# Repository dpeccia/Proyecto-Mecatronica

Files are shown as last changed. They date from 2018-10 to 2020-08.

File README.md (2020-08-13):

# Driller

#### Proyecto Final Grupal - Tecnicatura en Mecatrónica - Camada 2018

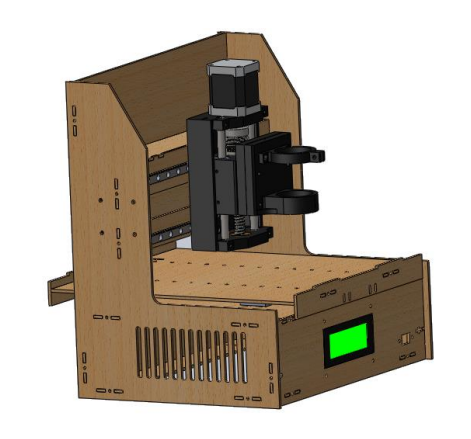
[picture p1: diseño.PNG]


Este proyecto fue realizado por toda la camada 2018 del estudio terciario _Mecatrónica_ brindado por  la _Cámara de Comercio e Industria Argentino-Alemana **(AHK)**_ en formato de Sistema Dual Alemán.

Consiste en una _Agujereadora Automática de Plaquetas Electrónicas_,  para acelerar y optimizar el tiempo del proceso de producción de plaquetas

La parte teórica, en donde fue hecho este proyecto, se cursó en el _Centro de Formación Industrial_ del _Instituto Hölters Schule_ mientras que cada alumno realizó la parte práctica del terciario en una empresa capacitadora

Más información sobre la **Tecnicatura en Mecatrónica** en [la página de la AHK](https://www.ahkargentina.com.ar/formaciones/sistema-dual-aleman/tecnicatura-en-mecatronica)

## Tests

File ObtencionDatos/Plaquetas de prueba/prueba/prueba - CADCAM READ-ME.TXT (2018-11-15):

LABCENTER PROTEUS TOOL INFORMATION FILE
=======================================

In case of difficulty, please e-mail support@labcenter.co.uk

Tool set up for Proteus layout 'prueba.pdsprj'.
CADCAM generated at 01:32:39 p.m. on jueves, 18 de octubre de 2018.

File List
---------
Top Copper              : prueba - CADCAM Top Copper.GBR
Bottom Copper           : prueba - CADCAM Bottom Copper.GBR
Top Solder Resist       : prueba - CADCAM Top Solder Resist.GBR
Bottom Solder Resist    : prueba - CADCAM Bottom Solder Resist.GBR
Mechanical 1            : prueba - CADCAM Mechanical 1.GBR
Drill                   : prueba - CADCAM Drill.DRL
Netlist                 : prueba - CADCAM Netlist.IPC

Photoplotter Setup
------------------
Format: RS274X, ASCII, 4.3, metric, absolute, eob=*, LZO
Notes:  D=Diameter, S=Side, W=Width, H=Height, C=Chamfer, I=Index

D10	CIRCLE  D=1.016mm                                                         FLASH
D11	CIRCLE  D=0.2032mm                                                        DRAW 
D12	CIRCLE  D=1.27mm                                                          FLASH
D13	CIRCLE  D=0.127mm                                                         DRAW 
D14	CIRCLE  D=0.0635mm                                                        DRAW 

NC Drill Setup
--------------
Format: Excellon, ASCII, 4.3, metric, absolute, eob=<CR><LF>, no zero suppression.
Notes:  Tool sizes are diameters. Layer sets are in brackets - 0=TOP, 15=BOTTOM, 1-14=INNER.

T01	0.381mm (0-15) Plated

Layer Stackup
-------------
Top Solder Resist        : 0.01016mm  Resist
Top Copper               : 0.03556mm  Copper
Core                     : 1.48336mm  FR4
Bottom Copper            : 0.03556mm  Copper
Bottom Solder Resist     : 0.01016mm  Resist

[END OF FILE]

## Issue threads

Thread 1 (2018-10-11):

Secuencia Ajuste

chrisgko, 2018-10-11:
Hay que cambiar las esperas de datos desde el micro por threads o algo asi, para que no se cuelgue el programa, y también para poder ajustar los puntos de calibración.

Closed 2018-11-16.

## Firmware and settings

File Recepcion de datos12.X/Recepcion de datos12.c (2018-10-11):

#include <18F4550.h>
#include <stdlib.h>
#fuses HSPLL,NOWDT,NOPROTECT,NOLVP,NODEBUG,PLL5,CPUDIV1,VREGEN,MCLR,USBDIV,  // 48 MHz  para  el  USB y 48 MHz para  el resto del sistema
#use delay(clock=48000000)
#use rs232(baud=9600, xmit=pin_c6, rcv=pin_c7, bits=8, parity=N,stream=standard) 
#use i2c(Master,sda=PIN_B4, scl=PIN_B5, force_sw,fast)
#include <i2c_Flex_LCD.c>   
//#include <LCD420-FLEX.c>

#define sentidox PIN_D0
#define sentidoy PIN_D1
#define sentidoz PIN_D2
#define motorx PIN_D3
#define motory PIN_D4
#define motorz PIN_D5
#define cerox PIN_D6
#define ceroy PIN_D7
#define ceroz PIN_C0
#define profunz PIN_C1
#define dremel PIN_E0
#define enter PIN_E1
#define habilx PIN_E2
#define habily PIN_A0
#define habilz PIN_A1
#define canalb PIN_A2
#define buzzer PIN_A3

char ch;
char mech[5];
char datox[7];
char datoy[7];
int i, j, h, flagfin, salir;
int contador, contador1;
signed int32 x, y, xini, yini, pasosx, pasosy;
float broca, pasosxflot, pasosyflot;
int flagx, flagy, flagxy, flagcomienzo, flagmecha, flagboton;
short int flagpaquete, flagajuste, flagcambiomecha;
signed int32 pasosz, zini, z, alturamecha, guarda;

void moverz(void) 
{
    output_low(habilz);
    pasosz = z - zini;
    
    while (pasosz > 0) 
    {
        output_high(sentidoz); //para abajo
        output_high(motorz);
        delay_us(1200);
        output_low(motorz);
        delay_us(1200);
        pasosz = pasosz - 1;
    }
    while (pasosz < 0) 
    {
        output_low(sentidoz); //para arriba
        output_high(motorz);
        delay_us(1200);
        output_low(motorz);
        delay_us(1200);
        pasosz = pasosz + 1;
    }
    zini = z;
}

void bajarz(void) 
{
    while (pasosz > 0) //rutina que baja el cabezal
    { 
        output_low(habilz);
        pasosz = pasosz - 1;
        output_high(sentidoz);
        output_toggle(motorz);
        delay_us(1200);
    }
}

void subirz(void) 
{
    while (pasosz > 0) //rutina que sube el cabezal
    { 
        output_low(sentidoz);
        pasosz = pasosz - 1;
        output_toggle(motorz);
        delay_us(1200);
    }
}

void conversionpasos(void) 
{
    pasosxflot = (x - xini) / 200.0;
    pasosyflot = (y - yini) / 200.0;
    if (pasosxflot >= 0)
        pasosx = (signed long int) (pasosxflot + 0.5);
    else
        pasosx = (signed long int) (pasosxflot - 0.5);

    if (pasosyflot >= 0)
        pasosy = (signed long int) (pasosyflot + 0.5);
    else
        pasosy = (signed long int) (pasosyflot - 0.5);

    pasosx = pasosx * 2;
    pasosy = pasosy * 2;
}



void moverxy(void) 
{
    clear_interrupt(INT_TIMER0);
    set_timer0(230);
    enable_interrupts(INT_TIMER0); //Habilita interrupción timer0
    flagx = 1;
    flagy = 1;
    flagxy = 1;
    while (flagxy == 1);
}

void posicionmecha(void) 
{
    x = +175000;
    y = +205000;
    conversionpasos();
    xini = x;
    yini = y;
    // pasosx=+1500;     //pasos para ir a punto de prueba
    //pasosy=+1000;     //pasos para ir a puto de prueba
    contador = 2;
    moverxy();
    putc('M');
}

void profundidadmecha(void) 
{
    printf(LCD_PUTC, "\f\1%s", "Ajustando Z");
    printf(LCD_PUTC, "\2%s", "Profundidad de mecha");
    output_low(habilz);
    output_low(habilx);
    output_low(habily);
    output_low(motorz);
    while (input(profunz) == 1) {
        output_high(sentidoz);
        output_high(motorz);
        delay_us(1200);
        output_low(motorz);
        delay_us(1200);
        alturamecha = alturamecha + 1;
    }
    // alturamecha=alturamecha-500; //le resta el espesor de la base + 1mm total 4,5 mm
    zini = alturamecha;
}

void ajusteceroz(void) 
{
    //printf(LCD_PUTC, "\f\1%s", "Ajustando eje Z");
    //printf(LCD_PUTC, "\2%s", "Espere por favor");
    output_low(habilz);
    printf(LCD_PUTC, "\f\1%s", "Buscando cero Z");
    while ((input(ceroz)) == 0) {
        output_low(sentidoz);
        output_toggle(motorz);
        delay_us(1200);
    }
    printf(LCD_PUTC, "\f\1%s", "Buscando cero Z OK");
    zini = 0;
}

void ajusteceroxy(void) 
{
    printf(LCD_PUTC, "\f\1%s", "Ajustando ejes X-Y");
    printf(LCD_PUTC, "\2%s", "Espere por favor");
    //ajusteceroz();
    output_low(habilx);
    output_low(habily);
    while ((input(cerox) == 0) || (input(ceroy)) == 0) 
    {
        if (input(cerox) == 0) 
        {
            output_high(sentidox);
            output_toggle(motorx);
        }
        if (input(ceroy) == 0) 
        {
            output_low(sentidoy);
            output_toggle(motory);
        }
        delay_us(1200);
    }
    output_low(motorx);
    output_low(motory);
    output_low(motorz);
    xini = 0;
    yini = 0;
}

void mecha(void) 
{
    while (flagmecha == 0);
    while (flagmecha == 1);
    broca = atof(mech);
}

void bip(void) 
{
    output_high(buzzer);
    contador1 = 5; // 1/48*4*65586*8*23=218453useg aprox
    clear_interrupt(INT_TIMER1); //limpio la bandera
    set_timer1(0);
    enable_interrupts(INT_TIMER1);
}

#INT_EXT2         //Atención a interrupción por cambio en RB2

void ext_isr1() //Función de interrupción
{ 
    putc('F');
    flagajuste = 0;
    salir = 1;
    // disable_interrupts(int_ext2_L2H);
}

#INT_EXT         //Atención a interrupción por cambio en RB0

void INTEXT_isr(void) //Función de interrupción
{ 
    output_low(motorz);
    if (input(canalb) == 0) 
    {
        output_low(habilz);
        output_low(sentidoz); //mecha para arriba
        z = z - 1;
        output_high(motorz);
        delay_us(1200);
        output_low(motorz);
        delay_us(1200);
    }
    if (input(canalb) == 1) 
    {
        output_low(habilz);
        output_high(sentidoz); //mecha para abajo
        z = z + 1;
        output_high(motorz);
        delay_us(1200);
        output_low(motorz);
        delay_us(1200);
    }
}
#int_TIMER0

void TIMER0_isr(void) 
{
    contador = contador - 1;

    if (contador == 0) 
    {
        contador = 2;
        if (pasosx == 0) 
        {
            flagx = 0;
        }
        if (pasosx > 0) 
        {
            output_low(sentidox);
            output_toggle(motorx);
            pasosx = pasosx - 1;
        }
        if (pasosx < 0) 
        {
            output_high(sentidox);
            output_toggle(motorx);
            pasosx = pasosx + 1;
        }

        if (pasosy == 0) 
        {
            flagy = 0;
        }
        if (pasosy > 0) 
        {
            output_high(sentidoy);
            output_toggle(motory);
            pasosy = pasosy - 1;
        }
        if (pasosy < 0) 
        {
            output_low(sentidoy);
            output_toggle(motory);
            pasosy = pasosy + 1;
        }

        if (flagx == 0 && flagy == 0) 
        {
            flagxy = 0;
            disable_interrupts(INT_TIMER0); //deshabilita interrupción timer0
        }

    }
    set_timer0(230); //Se recarga el timer0
}

#int_TIMER1

void TIMER1_isr(void) // Timer para buzzer
{
    contador1 = contador1 - 1;

    if (contador1 == 0) 
    {
        output_low(buzzer);
        disable_interrupts(INT_TIMER1);
    }
    set_timer1(0);
}
#int_rda

void serial_isr() 
{
    ch = getchar();
    
    if (ch == 'A') //Inicio Ajuste
    {
        flagajuste = 1;
    }    
    if (ch == 'S') 
    {
        flagcomienzo = 1;
    }
    if (ch == 'P') //Dato de perforacion entrante
    {
        flagpaquete = 1;
    }
    if (ch == 'F' && flagpaquete == 1) //Ciclo terminado
    {
        flagpaquete = 0;
        flagfin = 1;
    }
    if (ch == 'C')
    {
        flagpaquete = 0;
        flagcambiomecha = 1;
    }
    if (ch == 'M') //Mecha entrante    
    {        
        flagmecha = 1;
        h = 0;
    }
    if ((flagmecha) == 1 && (ch != 'M')) //Dato mecha
    {
        mech[h] = ch;
        h = h + 1;
        if (h == 5) 
        {
            flagmecha = 0;
        }
    }
    if (ch == 'X') //Valor X entrante
    {
        flagx = 1;
        i = 0;
    }
    if (ch == 'Y') //Valor Y entrante
    {
        flagy = 1;
        j = 0;
    }
    if ((flagx) == 1 && (ch != 'X')) //Dato X
    {
        datox[i] = ch;
        i = i + 1;
        if (i == 7) 
        {
            flagx = 0;
        }
    }
    if ((flagy) == 1 && (ch != 'Y')) //Dato Y
    {
        datoy[j] = ch;
        j = j + 1;
        if (j == 7) {
            flagy = 0;
            flagxy = 1;            
        }
    }
}
void perforacion(void) 
{
    output_high(dremel);
    while (flagpaquete == 0)
    {
        if(flagcambiomecha == 1)
        {
            ajusteceroz();
                ajusteceroxy();
                posicionmecha();
                putc('M');
                mecha();
                lcd_putc("\f\1Por favor coloque");
                printf(lcd_putc"\2mecha de %01.2fmm y", broca);
                lcd_putc("\3presione enter");

                while (input(enter) == 0);
                delay_ms(10);
                bip();
                while (input(enter) == 1);
                alturamecha = 0;
                profundidadmecha();
                zini = alturamecha;
                z = alturamecha - 500;
                moverz();
                ajusteceroxy();
                flagcambiomecha = 0;
                flagcomienzo = 1;
                puts("C");  // Confirmacion cambio de mechareturn;
                return;
        }
    }
    while (flagpaquete == 1) 
    {
        while (flagxy == 0)
        {
            if(flagpaquete == 0)
            {
                    return;
            }
        }        
        while (flagxy == 1) 
        {
            x = (signed long long int) atof(datox);
            y = (signed long long int) atof(datoy);
            conversionpasos();
            xini = x;
            yini = y;
            clear_interrupt(INT_TIMER0);
            set_timer0(230);
            enable_interrupts(INT_TIMER0); //Habilita interrupción timer0
            flagx = 1;
            flagy = 1;
            while (flagxy == 1);
            z = zini + 400; // Baja 4 mm
            moverz();
            z = zini - 400; //sube 4mm
            moverz();            
            flagpaquete = 0;
            putc('*');
        }
    }
    output_low(dremel);
}
void main() 
{
    delay_ms(1000);
    enable_interrupts(INT_RDA);
    setup_timer_0(RTCC_8_BIT | RTCC_DIV_256); //Configuración timer0
    setup_timer_1(T1_INTERNAL | T1_DIV_BY_8); //Configuración timer1

    enable_interrupts(INT_EXT2_L2H); //Habilita int. RB2?
    //ext_int_edge(L_TO_H);              //por flanco de subida
    enable_interrupts(GLOBAL); //Habilita interrupción general
    lcd_init();

    while (1) {
        flagfin = 0;
        flagmecha = 0;
        flagcomienzo = 0;
        xini = 0;
        yini = 0;
        zini = 0;
        flagajuste = 0;
        flagpaquete = 0;
        pasosx = 0;
        pasosz = 0;
        pasosy = 0;
        alturamecha = 0;
        x = 0;
        y = 0;
        z = 0;
        flagboton = 0;
        flagxy = 0;
        flagx = 0;
        flagy = 0;
        broca = 0;
        pasosxflot = 0;
        pasosyflot = 0;
        salir = 0;
        i = 0;
        j = 0;
        h = 0;
        output_high(habilx); //motores sin energía
        output_high(habily);
        output_high(habilz);
        output_low(dremel); //apago el dremel
        output_low(buzzer); // apago buzzer
        lcd_putc("\fHAGA CLICK EN");
        lcd_putc("\2CALIBRAR EN LA");
        lcd_putc("\3COMPUTADORA Y ESPERE");
        lcd_putc("\4UN MOMENTO.");
        while (flagcomienzo == 0);
        flagcomienzo = 0;
        ajusteceroz();
        ajusteceroxy();
        posicionmecha();
        mecha();
        printf(lcd_putc"\f\1Coloque mecha %01.2fmm", broca);
        lcd_putc("\2Presione enter para");
        lcd_putc("\3comenzar el ajuste");
        lcd_putc("\4de la placa.");
        while (input(enter) == 0);
        delay_ms(10);
        bip();
        while (input(enter) == 1);
        alturamecha = 0;
        profundidadmecha();
        zini = alturamecha;
        z = alturamecha - 500; 
        moverz();
        ajusteceroxy();
        putc('A');
        while (flagajuste == 0 && salir == 0);
        while (flagajuste == 1)
        {
            while (flagxy == 0);
            while (flagxy == 1)
            {
                x = (signed long long int) atof(datox);
                y = (signed long long int) atof(datoy);
                conversionpasos();
                xini = x;
                yini = y;
                clear_interrupt(INT_TIMER0);
                set_timer0(230);
                enable_interrupts(INT_TIMER0); //Habilita interrupción timer0
                flagx = 1;
                flagy = 1;
                while (flagxy == 1);
                lcd_putc("\f\1Gire para subir o");
                lcd_putc("\2bajar mecha.Presione");
                lcd_putc("\3enter nuevo punto.");
                lcd_putc("\4Boton rojo salir.");
                clear_interrupt(INT_EXT_L2H);
                enable_interrupts(INT_EXT_L2H);
                while (input(enter) == 0 && salir == 0);
                delay_ms(10);
                bip();
                while (input(enter) == 1 && salir == 0);
                if (input(enter) == 0 && salir == 0)
                {
                    guarda = zini;
                    zini = z;
                    z = guarda;
                    moverz();
                    putc('A');
                }
            }
        }
        
        bip();
        disable_interrupts(INT_EXT_L2H);
        
        /*while (flagfin == 0) 
        {
            /*
            if (salir == 0)
            {
                ajusteceroz();
                ajusteceroxy();
                posicionmecha();
                putc('M');
                mecha();
                lcd_putc("\f\1Por favor coloque");
                printf(lcd_putc"\2mecha de %01.2fmm y", broca);
                lcd_putc("\3presione enter");

                while (input(enter) == 0);
                delay_ms(10);
                bip();
                while (input(enter) == 1);
                alturamecha = 0;
                profundidadmecha();
                zini = alturamecha;
                z = alturamecha - 500;
                moverz();
                ajusteceroxy();
                flagcambiomecha = 0;
                flagcomienzo = 1
                puts("C");  // Confirmacion cambio de mecha
            }*/
            ajusteceroxy();
            contador = 2;
            lcd_putc("\f\1Perforadora Lista");
            lcd_putc("\2para operar haga click");
            lcd_putc("\3en \"Comenzar\"");
            while (flagcomienzo == 0);
        while (flagfin == 0)
        {
            lcd_putc("\f\1PERFORANDO");
            flagcomienzo = 0;
            perforacion();
            salir = 0;
        }
    }
}

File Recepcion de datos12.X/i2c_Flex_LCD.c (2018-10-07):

//----------------------------------------------------------------------------- 
// Title:         i2c_Flex_LCD 
// Description:   Driver for common LCD with 1/2/3 or 4 row modules using PCF8574T interface board with I2C protocol. 
// Date:          Nov-2013 
// Ver.Rev.:      1.0 
// Author:        Hugo Silva (sergio-hugo@bol.com.br) #Based on the routines of 20X4_LCD_I2C_DRIVER.h from Pumrin S. 
//----------------------------------------------------------------------------- 
// 
// lcd_init() Must be called before any other function. 
// 
// lcd_putc(c) Will display c on the next position of the LCD. 
//  
//     \f Clear LCD dispay 
//     \1 Set write position on LCD Line 1 
//     \2 Set write position on LCD Line 2 
//     \3 Set write position on LCD Line 3 
//     \4 Set write position on LCD Line 4 
// 
//     lcd_gotoxy(x,y) Set write position on LCD (upper left is 1,1) 
// 
//----------------------------------------------------------------------------- 
// LCD pins D0-D3 are not used. 
//----------------------------------------------------------------------------- 
// 
// Commment   : Control of a compatible LCD HITACHI from a bus I2C with 
//              an EXPANDER of I/O with connection I2C. The tests of these 
//              routines have been programmed using the IC PCF8574T of Phillips. 
//              I used 4 bits mode programming. The 8 bits mode programming 
//              is possible if you use 2 x PCF8574T. 
// 
// As defined in the following structure the pin connection is as follows: 
// 
//  PCF8574P     LCD 
//  ========     ====== 
//     P0        RS 
//     P1        RW 
//     P2        Enable  
//     P3        Led Backlight 
//     P4        D4 
//     P5        D5 
//     P6        D6 
//     P7        D7 
// 
//  The SCL and SDA pins should be pull-up resistor as shown below: 
// 
//             +5v 
//               | 
//               < 
//               > 4.7K        
//               <          
//To PIC         |          To i2c slave 
//pin xx ------------------ SDA pin  
//(SDA)                      
//              +5v 
//               | 
//               < 
//               > 4.7K        
//               <          
//To PIC         |          To i2c slave 
//pin xx ------------------ SCL pin  
//(SCL) 
// 
//To PIC                    To i2c slave 
//Vss pin ----------------- Vss or ground pin  
//                | 
//              ----- 
//               ---  Ground 
//                -  
//  
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
#define LCD_ADDR       0x7E//0x4E //I2C slave address for LCD module 

#define ON             1 
#define OFF            0 
#define RS             0b00000001  //P0 - PCF8574T Pin connected to RS 
#define RW             0b00000010  //P1 - PCF8574T Pin connected to RW 
#define EN             0b00000100  //P2 - PCF8574T Pin connected to EN 
#define BACKLIGHT_LED  0b00001000  //P3 - PCF8574T Pin connected to BACKLIGHT LED 

#define lcd_line_one   0x80   // LCD RAM address for line 1 
#define lcd_line_two   0xC0   // LCD RAM address for line 2 
#define lcd_line_three 0x94   // LCD RAM address for line 3 
#define lcd_line_four  0xD4   // LCD RAM address for line 4 
  
byte address; 
int1 lcd_backlight=ON; 

void i2c_send_nibble(unsigned char data) 
   {    
        i2c_start(); 
        delay_us(1); 
        i2c_write(LCD_ADDR); //the slave addresse 
        delay_us(1); 
        i2c_write(data); 
        delay_us(1); 
        i2c_stop(); 
        delay_us(1); 
   } 

void lcd_send_byte(unsigned char data) 
   { 
        if (lcd_backlight) data=data|EN|BACKLIGHT_LED; else data=data|EN; //set pin EN 
        i2c_send_nibble(data); 
        data=data-4;       //toggle EN back to 0 
        i2c_send_nibble(data); 
   } 
    
void lcd_clear() 
{ 
    lcd_send_byte(0x00); 
    lcd_send_byte(0x10); 
    delay_ms(2); 
} 

void lcd_init() 
{ 
    delay_ms(10); //LCD power up delay 
        
   //Request works on the command by set the RS = 0 R/W = 0 write 
        lcd_send_byte(0x00); 
        lcd_send_byte(0x10); 
        lcd_send_byte(0x00); 
        lcd_send_byte(0x00); 
        lcd_send_byte(0x10); 
           //First state in 8 bit mode 
        lcd_send_byte(0x30); 
        lcd_send_byte(0x30); 
           //Then set to 4-bit mode 
        lcd_send_byte(0x30); 
        lcd_send_byte(0x20); 
           //mode 4 bits, 2 lines, characters 5 x 7 (28 h) 
        lcd_send_byte(0x20); 
        lcd_send_byte(0x80); 
           //no need cursor on (0Ch) 
        lcd_send_byte(0x00); 
        lcd_send_byte(0xC0); 
           //the cursor moves to the left (06 h) 
        lcd_send_byte(0x00); 
        lcd_send_byte(0x60); 
           //clears the display 
        lcd_clear(); 
} 

void lcd_gotoxy( byte x, byte y) 
{      
static char data; 
      
   switch(y) 
   { 
      case 1:  address= lcd_line_one;     break; 
      case 2:  address= lcd_line_two;     break; 
      case 3:  address= lcd_line_three;   break; 
      case 4:  address= lcd_line_four;    break; 
      default: address= lcd_line_one;     break;  
   } 
  
   address+=x-1; 
   data=address&0xF0; 
   lcd_send_byte(data); 
   data=address&0x0F; 
   data=data<<4; 
   lcd_send_byte(data); 
} 

//Display the character on LCD screen. 
void LCD_PUTC(char in_data) 
{ 
 char data;      
  switch(in_data) 
   {  
     case '\f': lcd_clear()    ;  break;                
     case '\1': lcd_gotoxy(1,1);  break; 
     case '\2': lcd_gotoxy(1,2);  break; 
     case '\3': lcd_gotoxy(1,3);  break; 
     case '\4': lcd_gotoxy(1,4);  break; 

     default: 
        data=in_data&0xF0; 
        data=data|RS; //set RS pin to 1 
        lcd_send_byte(data); 
        data=in_data&0x0F; 
        data=data<<4; 
        data=data|RS; //set RS pin to 1 
        lcd_send_byte(data); 
     break; 
   } 
} 

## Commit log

2018-09-10 Botones de calibracion
2018-09-28 Ultima version con la sim del micro
2018-10-13 Secuencia Modificada
    Se usa Recibir() que maneja toda la secuencia. Por ahora se queda en perforacion, hay que terminarla y revisar si se hacen bien los puntos de ajuste punto1 y punto2
2018-10-19 Nueva Secuencia
    El programa lee ahora DOS archivos, uno con todos los agujeros (el Drill) y otro con las esquinas de la plaqueta (Mechanical). El ajuste se realiza llevando la mecha a las esquinas, hasta recibir un 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
2018-11-07 Revisión de Leer_Archivo
2018-11-07 Ajuste con esquinas + puntos internos
    Realiza el ajuste posicionándose en las esquinas y en dos de los puntos internos de la placa.
    Falta visualizar esos dos puntos gráficamente.
2018-11-15 Visualización de ajuste y agujeros
    Ya se pueden ver todos los agujeros, así como también el ajuste.
    Falta terminar de arreglar bugs y excepciones por los que puede fallar. (Formato de archivo incorrecto)
    Falta revisar y dejar definitiva la secuencia de elección de los agujeros extremos (por ahora elige, si hay dos mechas o mas, la segunda si es del doble o menos de la mas primera (están ordenados por tamaño)).
2018-11-15 Plaquetas para ir probando
    La del proyecto es Recepción de datos 13
    [Recepcion de datos13 - CADCAM Bottom Copper.GBR, Recepcion de datos13 - CADCAM Drill.DRL, Recepcion de datos13 - CADCAM Drill.GBR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]
2018-11-16 Version Final Funcionando
    Reparadas excepciones. Se puede volver a abrir un archivo para proxima secuencia sin tener que cerrar el programa.
    Se desactivó el CheckForIllegalCrossThreads.
    Se realizan capturas para el manual.
2018-11-16 Version Final - Arreglado reinicio de secuencia
    Una vez terminado el perforado, se puede volver a comenzar sin seleccionar nuevos archivos, usando los ultimos seleccionados.
2018-11-22 Visualización de agujeros arreglada
    Los agujeros ahora se muestran rotados 180 grados, para que sea mas acorde al momento de perforado de la placa.
2018-11-30 Version para la exposicion
    Se ajusta con todas las esquinas. Arreglado el graficador.
